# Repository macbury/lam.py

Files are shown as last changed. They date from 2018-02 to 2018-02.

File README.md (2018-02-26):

# lam.py

Led lamp that displays information about current jenkins build status. Main features:

* Automaticaly turn on/off if user is logged on Hipchat
* Beam effect if somebody makes coffee([How i know that](http://codesthq.com/blog/2016/how-did-we-hack-coffeemaker-and-had-fun-with-it.html))
* Unicorn effect if food is delivered(via. [lunching.pl](http://lunching.pl))
* Big red arcade button that can send random message to somebody on Hipchat
* Change color depending on [Jenkins](https://jenkins.io/) build status

## How it works:
On separate server(in my case Raspberry Pi under my couch), there is running python script that periodically fetch information from jenkins and other endpoints. Any change is then published to separate MQTT topic. Each lamp subscribe to topics and animates acording to event:

[See it in action on YouTube](https://www.youtube.com/watch?v=UrOeL2-fV0c)

### Failing builds
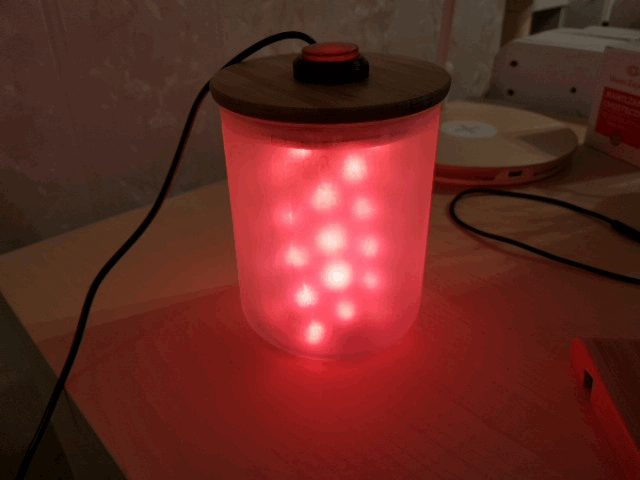
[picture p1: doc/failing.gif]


### Running builds
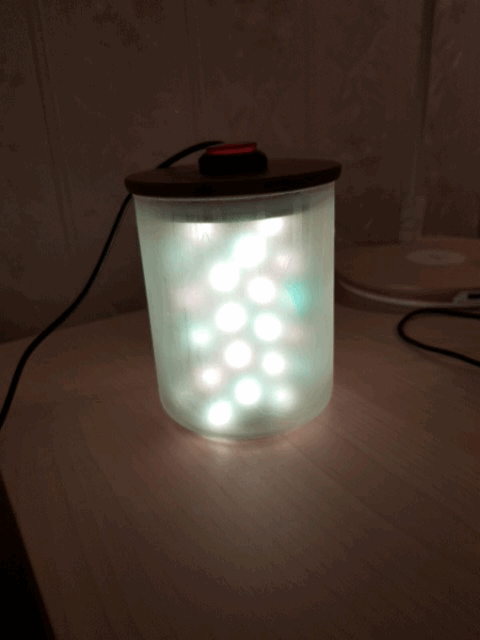
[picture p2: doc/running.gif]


### Success builds
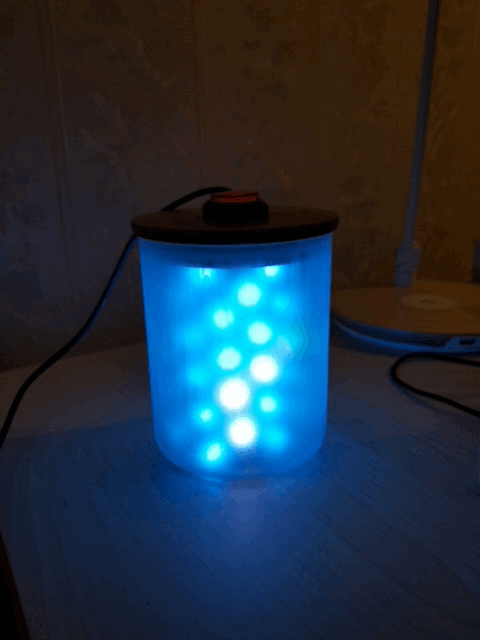
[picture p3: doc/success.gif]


## Requirements

* [IKEA Jar EKLATANT](http://www.ikea.com/pl/pl/catalog/products/10376601/)
* [Arcade button(everything is better with arcade button)](https://www.aliexpress.com/item/6pcs-lot-illuminated-Arcade-Push-Button-5V-LED-Arcade-Button-With-Microswitch-To-Arcade-Machine-Game/32807322244.html)
* [WeMos D1 Mini v2](https://www.aliexpress.com/item/D1-mini-V2-Mini-NodeMcu-4M-bytes-Lua-WIFI-Internet-of-Things-development-board-based-ESP8266/32681374223.html)
* [NeoPixel 5V LED RGB WS2812B strip](https://www.aliexpress.com/item/1M-5M-WS2812B-led-strip-30-60-74-90-96-144leds-DC5V-dearm-color-pixel-strip/32688092455.html)
* Wires(of curse)
* Toilet paper inner tube
* 5V/4A power source DC 5,5 / 2,5mm
* Frozen glass spray
* Server with LINUX to run python script and MQTT server

## Preparing device

### Make hole in the lid of the jar and put arcade button
Additionaly add small hole for power coord.
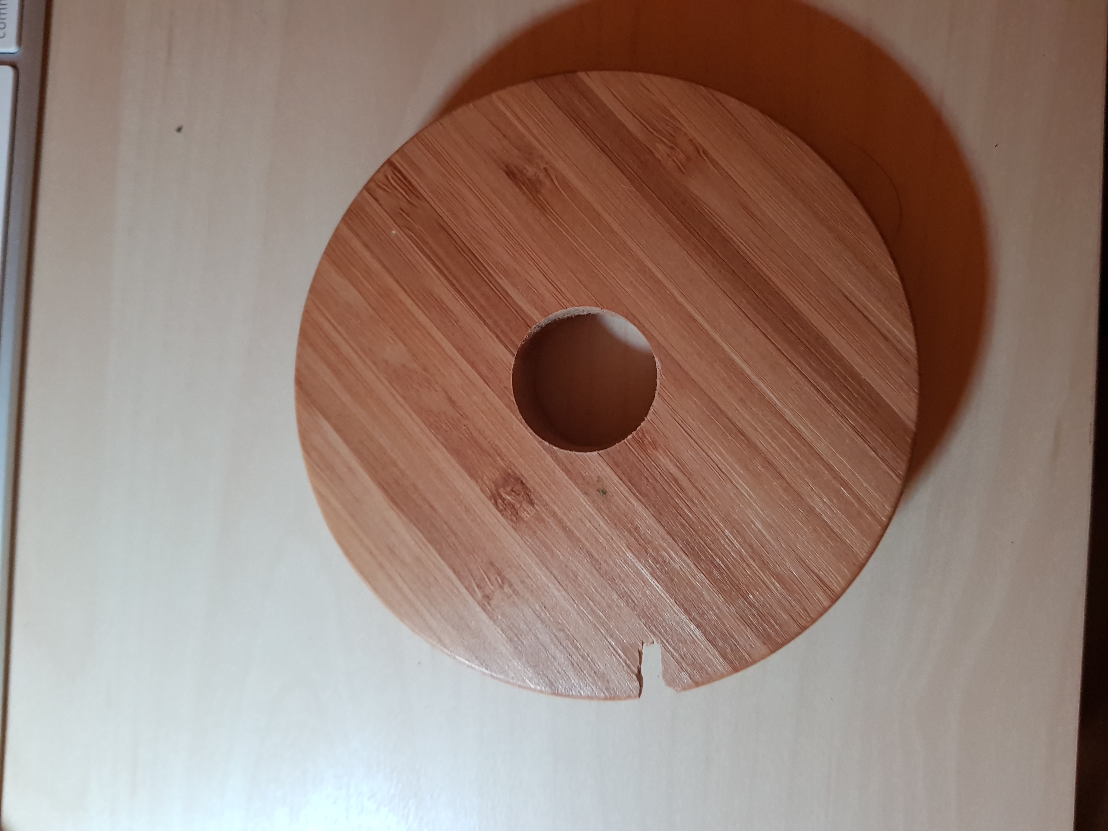
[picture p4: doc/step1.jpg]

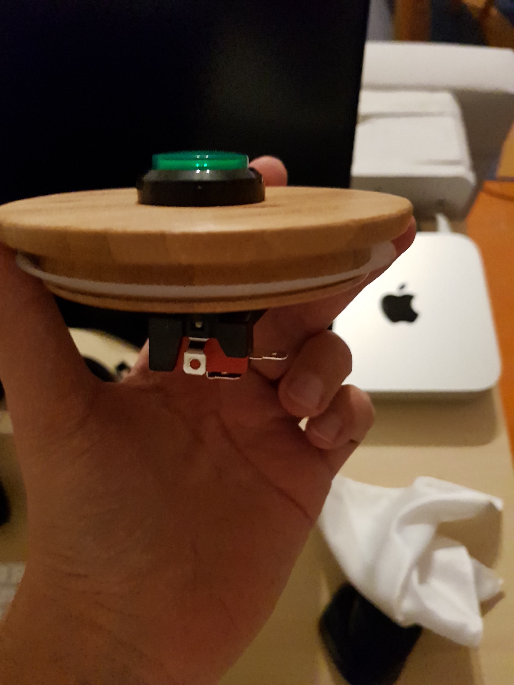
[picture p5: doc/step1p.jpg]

### Apply frozen glass effect to glass jar
I needed to apply 3 coatings before it look cool.
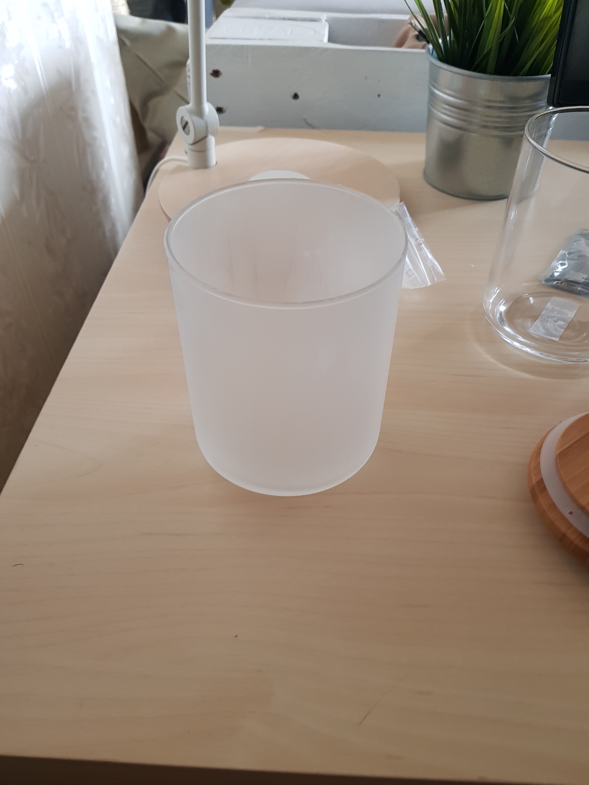
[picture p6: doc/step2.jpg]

### Wire and solder device
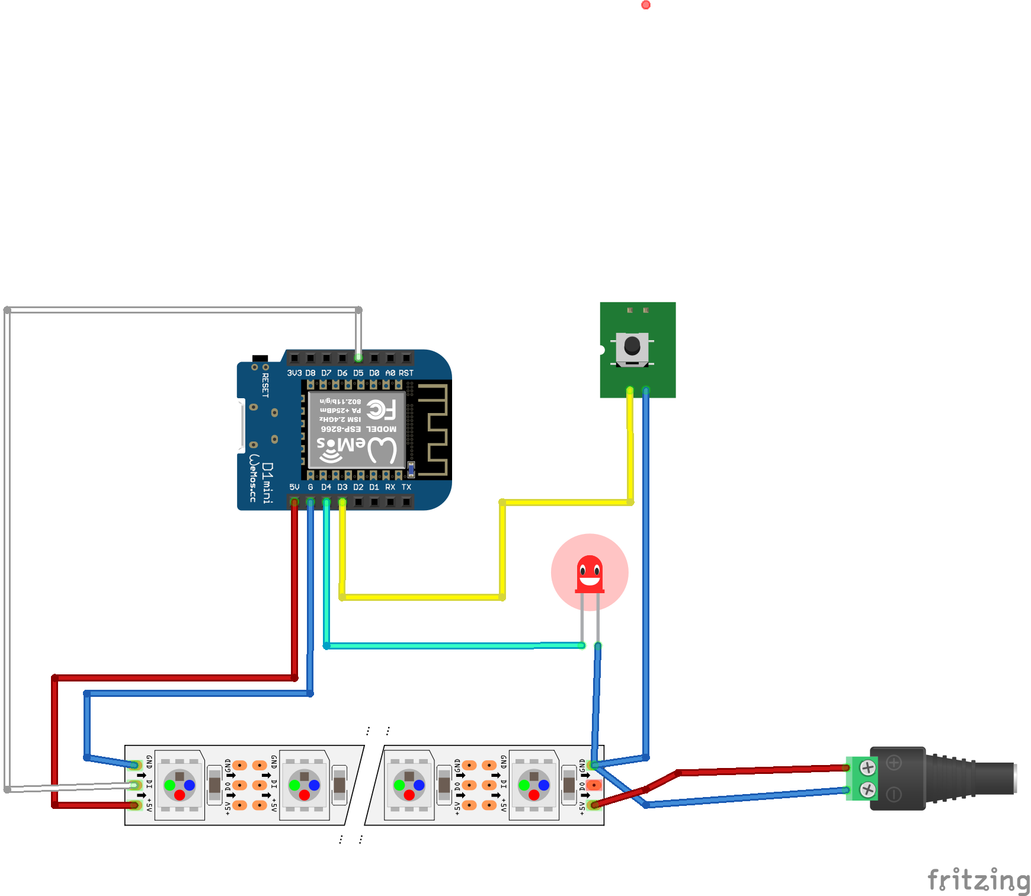
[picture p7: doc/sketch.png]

### Wrap the tube using led strip and connect elements
Mount tube using tape, and put everything inside.
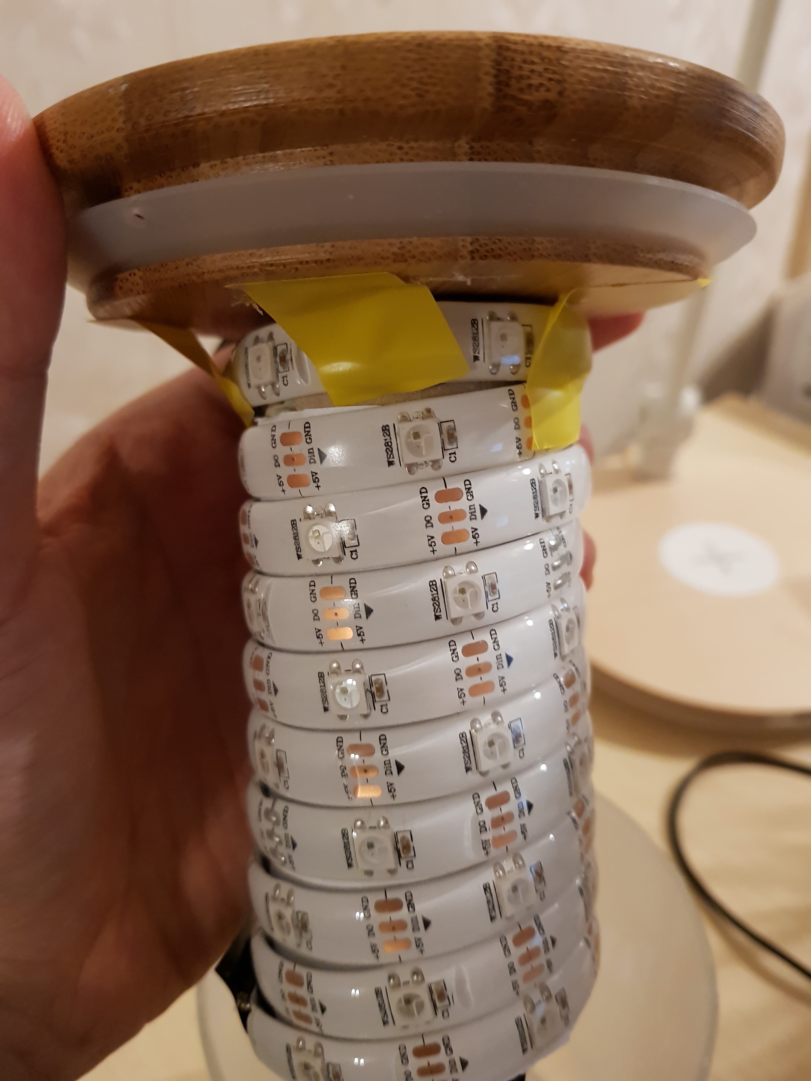
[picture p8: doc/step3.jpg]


### Upload code to Wemos D1 mini

Open `device/device.ino` in arduino ide. Copy `credentials.h.example` to `credentials.h`. Update it with your credentials and upload to Wemos D1.

## Configuration of server

After cloning run:

```
pip3 install -r requirements.txt
```

Edit home configuration under `config.yaml` and run it:

```
python3 src/lam.py
```

## Example systemd service file

```
sudo cp systemd/lam.py.service /lib/systemd/system/
sudo systemctl enable lam.py
sudo systemctl start lam.py
```

## Free MQTT brokers

* https://github.com/mqtt/mqtt.github.io/wiki/public_brokers
* https://customer.cloudmqtt.com/login

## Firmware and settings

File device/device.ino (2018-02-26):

#include <EEPROM.h>

#include <Adafruit_NeoPixel.h>
#include <ArduinoJson.h>
#include <ESP8266WiFi.h>
#include <PubSubClient.h>
#include <ESP8266mDNS.h>
#include <WiFiUdp.h>
#include <ArduinoOTA.h>

#include "credentials.h"

const byte TICK_DELAY = 10;
char * currentState = "";
int maxBrightness = LIGHT_BRIGHTNESS;
int currentBrightness = 0;
bool teamOnline;

WiFiClient espClient;
PubSubClient client(espClient);
Adafruit_NeoPixel strip = Adafruit_NeoPixel(PIXEL_COUNT, PIN_LED_STRIP, NEO_GRB + NEO_KHZ800);

#include "effects.h"
#include "button.h"
#include "connection.h"
#include "state.h"

void on_mqtt_message(char* topic, byte* payload, unsigned int length) {
  Serial.print("Topic: ");
  Serial.println(topic);
  if (strcmp(topic, MQTT_TOPIC_FOOD) == 0) {
    foodAlertEffect();
  } else if (strcmp(topic, MQTT_TOPIC_COFFEE) == 0) {
    coffeeEffect(payloadToInt(payload, length));
  } else if (strcmp(topic, MQTT_TOPIC_PRESENCE) == 0) {
    Serial.println("Topic presence");
    turnOnOff(payload, length);
  } else if (strcmp(topic, MQTT_TOPIC_BRIGHTNESS) == 0) {
    Serial.println("Changing brightness");
    setBrightness(payloadToInt(payload, length));
  } else if (strcmp(topic, MQTT_TOPIC_BUILD) == 0) {
    switchToState(payload, length);
  } else {
    Serial.println("Unhandled!");
  }
}

void setup() {
  Serial.begin(115200);
  delay(10);

  randomSeed(100);
  pinMode(PIN_STATUS_LED, OUTPUT);
  pinMode(PIN_ACTION_BUTTON, INPUT);
  analogWrite(PIN_STATUS_LED, 255);

  client.setServer(MQTT_HOST, MQTT_PORT);
  client.setCallback(on_mqtt_message);

  strip.begin();
  delay(100);
  currentEffect = new ClearEffect();
}

void loop() {
  if (client.connected()) {
    client.loop();
    ArduinoOTA.handle();
    updateButtonLed();
    handleButton();
    handleLight();
  } else {
    if (ensureMqttConnection()) {
      onConnect();
    }
  }

  delay(TICK_DELAY);
}

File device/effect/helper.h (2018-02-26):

int buttonLedBrightness = 0;
int buttonLedFadeAmount = 20;

void updateButtonLed() {
  buttonLedBrightness += buttonLedFadeAmount;
  if (buttonLedBrightness < 0) buttonLedBrightness = 0;
  if (buttonLedBrightness > 1023) buttonLedBrightness = 1023;

  if (buttonLedBrightness == 0 || buttonLedBrightness == 1023) {
    buttonLedFadeAmount = -buttonLedFadeAmount;
  }
  analogWrite(PIN_STATUS_LED, buttonLedBrightness);
}

void clearColor() {
  strip.setBrightness(0);
  for(int i=0; i<strip.numPixels(); i++) {
    strip.setPixelColor(i, 0);
  }
  strip.show();
}

byte lerp(float progress, float fromValue, float toValue){
  return (int)(fromValue + (toValue - fromValue) * progress);
}

RGB lerpColor(float progress, RGB fromColor, RGB toColor) {
  return {
    lerp(progress, fromColor.r, toColor.r),
    lerp(progress, fromColor.g, toColor.g),
    lerp(progress, fromColor.b, toColor.b)
  };
}

void transitToEffect(Effect * fromEffect, Effect * toEffect, float transitionTime) {
  float step = (TICK_DELAY/transitionTime);
  for (float alpha = 0; alpha <= 1.0; alpha+=step) {
    fromEffect->update();
    toEffect->update();

    for(byte i=0; i<strip.numPixels(); i++) {
      RGB currentColor = fromEffect->get(i);
      RGB nextColor = toEffect->get(i);

      strip.setPixelColor(
        i,
        strip.Color(
          lerp(alpha, currentColor.r, nextColor.r),
          lerp(alpha, currentColor.g, nextColor.g),
          lerp(alpha, currentColor.b, nextColor.b)
        )
      );
    }

    strip.show();
    yield();
    delay(TICK_DELAY);
  }
}

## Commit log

2018-02-22 Pulsating button
2018-02-24 Effect for food and coffee
    [sketch.fzz]
2018-02-24 Sample step
